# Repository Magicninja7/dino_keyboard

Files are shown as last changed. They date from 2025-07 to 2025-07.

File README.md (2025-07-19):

# Description
A keyboard with 84 keys, a ssd1306 mini-display, and 2 ec11 potentiometers. It has a unque look, with lots of extra keys for ex. undo, copy, paste, print, etc. You can also control the brightness and volume with the knobs (yes, i change the brightness that often).
Why? i literally thought: hmm, a keyboard would look nice on my desk. And highway happened, so i actually did it! 

### CAD render
render
### PCB
pcb
### diagram
diagram

# BOM
| item | price | quantity | total | link |
| --- | --- | --- | ----- | ---- |
| ssd1306 | 2$ | 1 | 2$ | https://pl.aliexpress.com/item/1005007755490093.html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 |
| cherry mx switch | 33$ | 90 | 33$ | https://pl.aliexpress.com/item/1005007907313874.html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
| keycaps | 25$ | 125 | 25$ | https://www.ebay.com/itm/374554619019?var=643532147086&utm_source=chatgpt.com
| raspi pico | - | 2 | - | - |
| EC11 rotary encoder | 1$ | 2 | 2$ | https://kamami.pl/enkodery/1191644-modul-encoder-impulsator-ec11-20-impulsow-z-przyciskiem-rotary-enkoder-5906623487332.html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
| PCB | 45$ | 1 | 45$ | n/d

total w/ customs & shipping = ~150$  (yay customs & shipping costs, how lovely)

Note: the places where i placed -, means i already have that part so i don't need to purchase it

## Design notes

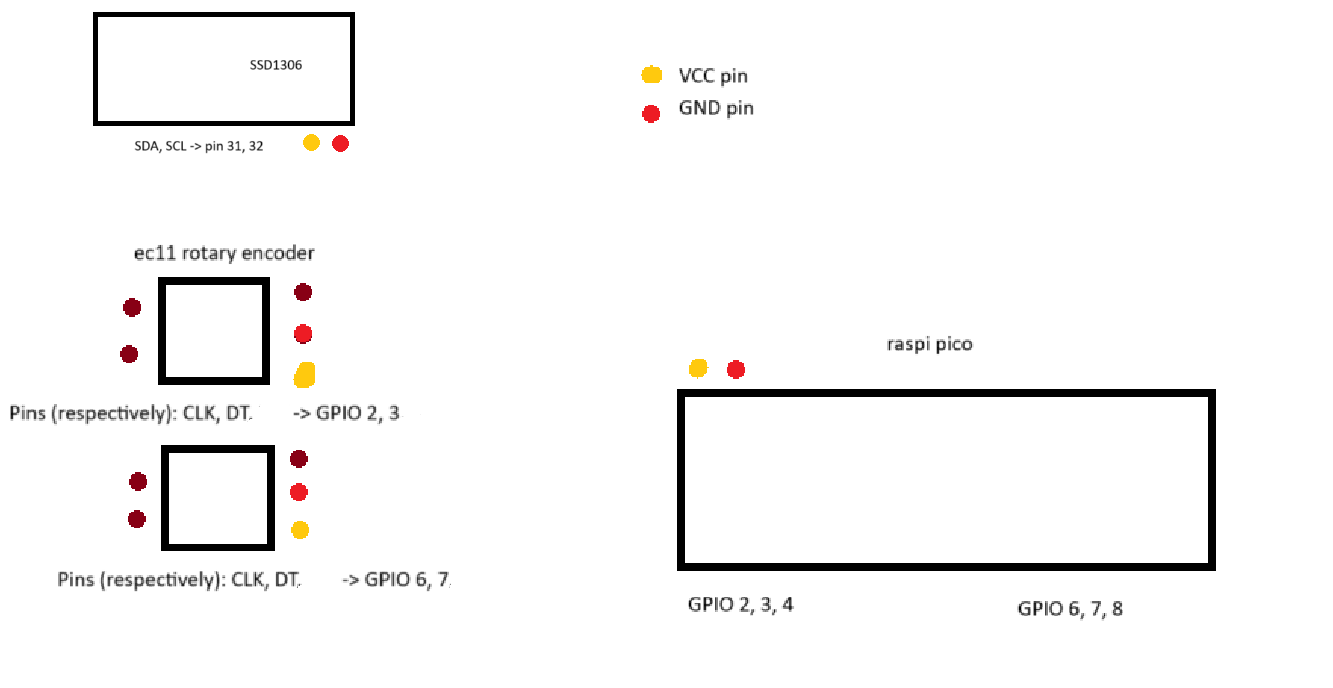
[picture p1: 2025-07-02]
diagram.png

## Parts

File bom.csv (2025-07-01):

item | price | quantity | total | link
ssd1306 | 2 | 1 | 2 | https://pl.aliexpress.com/item/1005007755490093.html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
cherry_mx_switch | 33 | 90 | 33 | https://pl.aliexpress.com/item/1005007907313874.html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
keycaps | 25 | 125 | 25 | https://www.ebay.com/itm/374554619019?var=643532147086&utm_source=chatgpt.com
raspi_pico | 8 | 2 | 16 | https://botland.com.pl/moduly-i-zestawy-do-raspberry-pi-pico/21574-raspberry-pi-pico-w-rp2040-arm-cortex-m0-cyw43439-wifi-5056561803173.html
ec11 | 1 | 2 | 2 | https://kamami.pl/enkodery/1191644-modul-encoder-impulsator-ec11-20-impulsow-z-przyciskiem-rotary-enkoder-5906623487332.html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
pcb | 45 | 1 | 45 | n/d

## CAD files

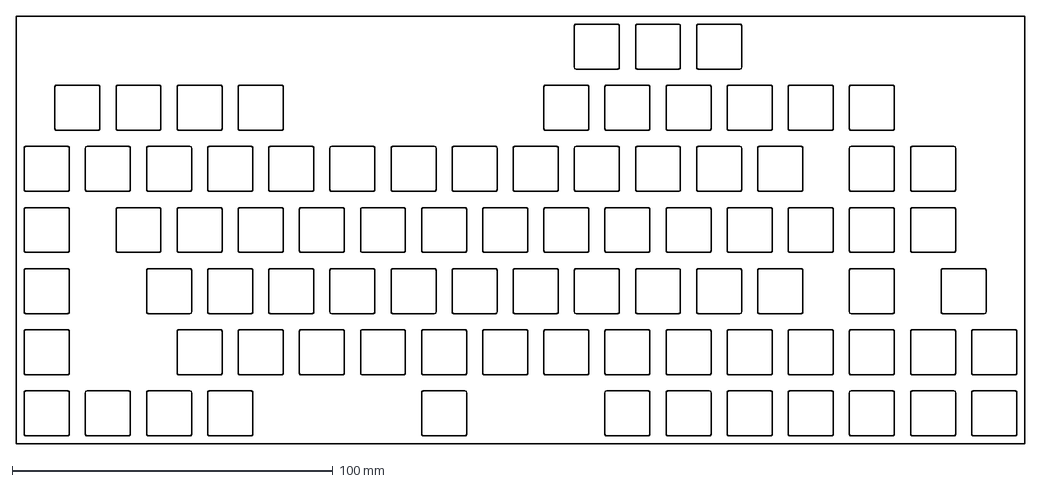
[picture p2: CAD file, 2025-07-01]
cad/plate-2025-05-24T16_50_25.808Z.dxf
314.3 x 133.3 mm

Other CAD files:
cad/EC11 Rotary Encoder Dode Switch-15mm .STEP
plate-2025-05-24T16_50_25.808Z.dxf

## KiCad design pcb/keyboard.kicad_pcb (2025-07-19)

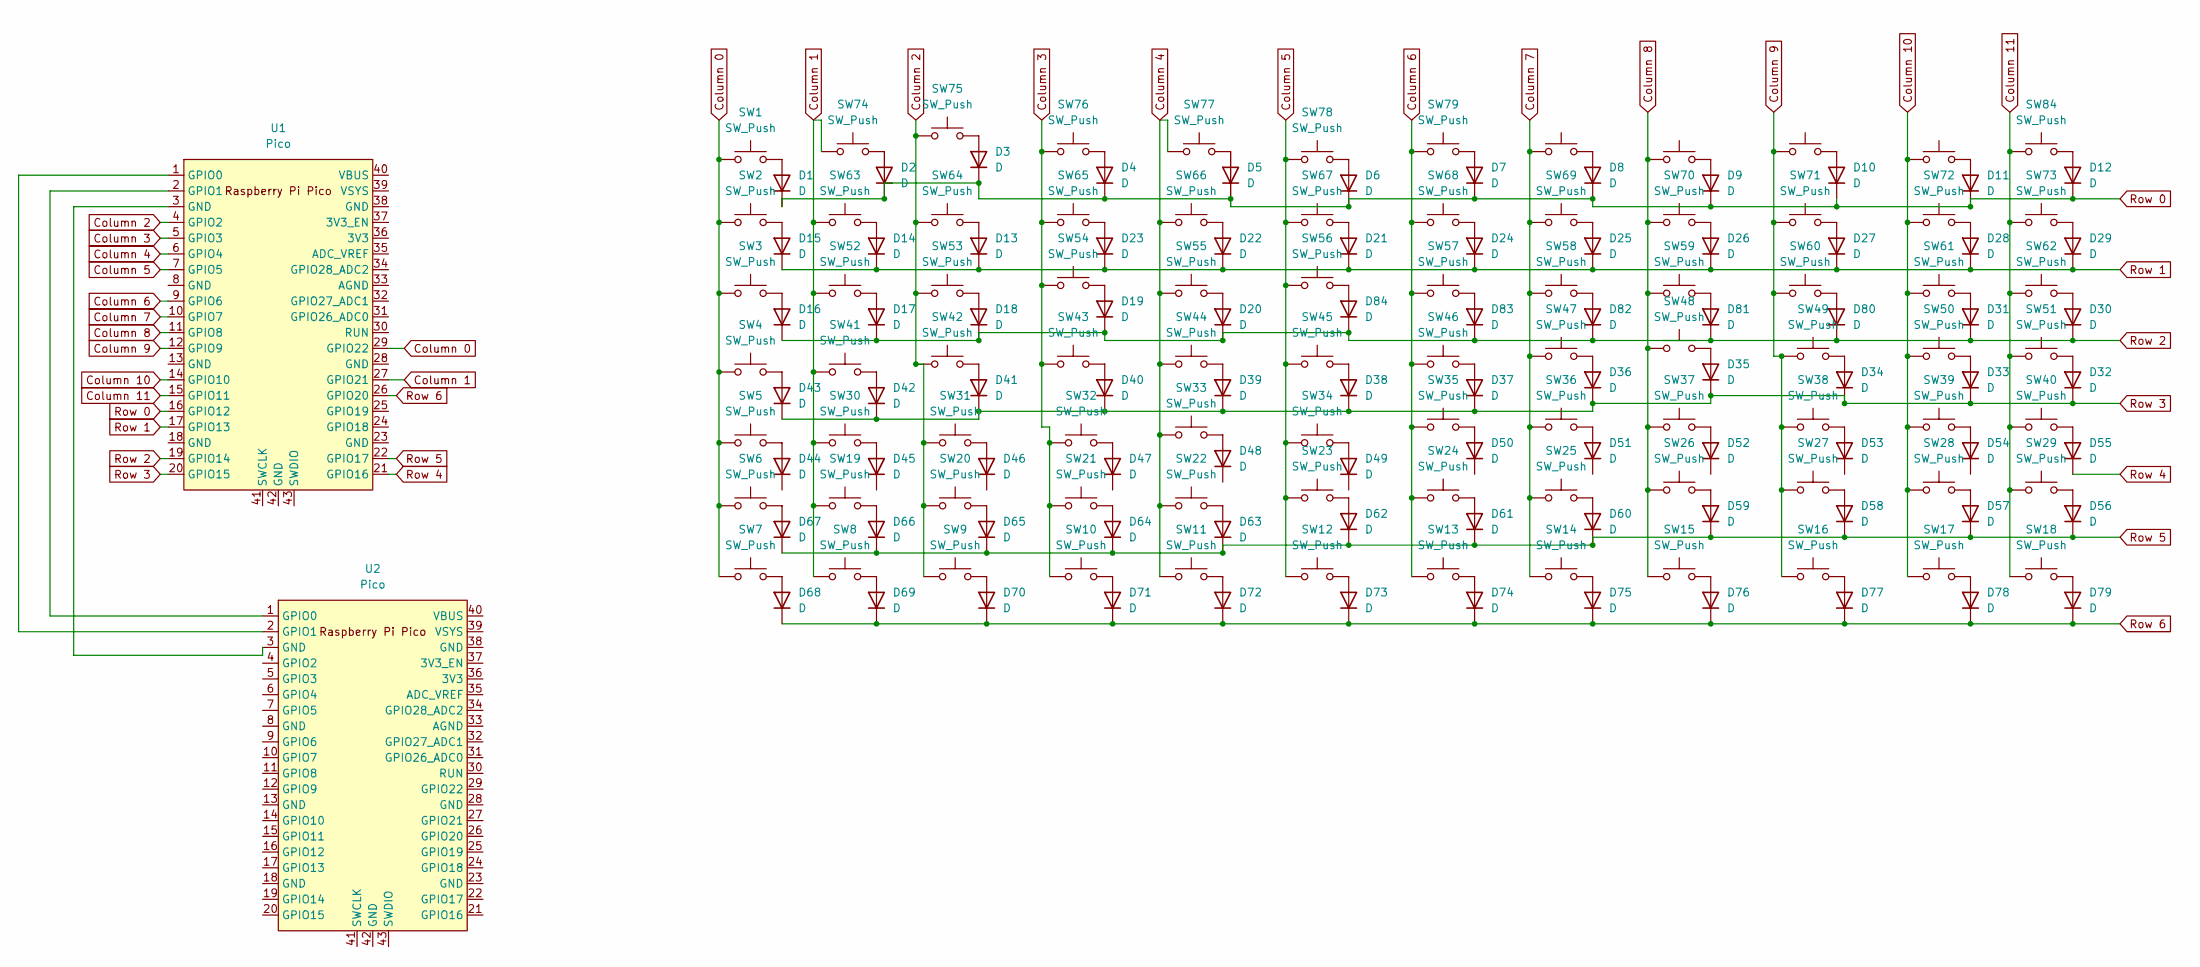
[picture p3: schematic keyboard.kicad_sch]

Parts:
D1, D2, D3, D4, D5, D6, D7, D8, D9, D10, D11, D12, D13, D14, D15, D16, D17, D18, D19, D20, D21, D22, D23, D24, D25, D26, D27, D28, D29, D30, D31, D32, D33, D34, D35, D36, D37, D38, D39, D40, D41, D42, D43, D44, D45, D46, D47, D48, D49, D50, D51, D52, D53, D54, D55, D56, D57, D58, D59, D60, D61, D62, D63, D64, D65, D66, D67, D68, D69, D70, D71, D72, D73, D74, D75, D76, D77, D78, D79, D80, D81, D82, D83, D84: D; LED_0201_0603Metric
SW1, SW2, SW3, SW4, SW5, SW6, SW7, SW8, SW9, SW10, SW11, SW12, SW13, SW14, SW15, SW16, SW17, SW18, SW19, SW20, SW21, SW22, SW23, SW24, SW25, SW26, SW27, SW28, SW29, SW30, SW31, SW32, SW33, SW34, SW35, SW36, SW37, SW38, SW39, SW40, SW41, SW42, SW43, SW44, SW45, SW46, SW47, SW48, SW49, SW52, SW53, SW54, SW55, SW56, SW57, SW58, SW60, SW61, SW62, SW63, SW64, SW65, SW66, SW67, SW68, SW69, SW70, SW71, SW72, SW73, SW74, SW75, SW76, SW77, SW78, SW79, SW80, SW81, SW82, SW83, SW84: SW_Push; SW_Cherry_MX_1.00u_PCB
SW50, SW51: SW_Push; SW_Cherry_MX_1.75u_PCB
SW59: SW_Push; SW_Cherry_MX_2.75u_PCB
U1, U2: Pico; RPi_Pico_SMD_TH

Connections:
Column 0: SW1.1, SW2.1, SW3.1, SW4.1, SW5.1, SW6.1, SW7.1, U1.29 (GPIO22)
Column 1: SW8.1, SW19.1, SW30.1, SW41.1, SW52.1, SW63.1, SW74.1, U1.27 (GPIO21)
Column 2: SW9.1, SW20.1, SW31.1, SW42.1, SW53.1, SW64.1, SW75.1, U1.4 (GPIO2)
Column 3: SW10.1, SW21.1, SW32.1, SW43.1, SW54.1, SW65.1, SW76.1, U1.5 (GPIO3)
Column 4: SW11.1, SW22.1, SW33.1, SW44.1, SW55.1, SW66.1, SW77.1, U1.6 (GPIO4)
Column 5: SW12.1, SW23.1, SW34.1, SW45.1, SW56.1, SW67.1, SW78.1, U1.7 (GPIO5)
Column 6: SW13.1, SW24.1, SW35.1, SW46.1, SW57.1, SW68.1, SW79.1, U1.9 (GPIO6)
Column 7: SW14.1, SW25.1, SW36.1, SW47.1, SW58.1, SW69.1, SW80.1, U1.10 (GPIO7)
Column 8: SW15.1, SW26.1, SW37.1, SW48.1, SW59.1, SW70.1, SW81.1, U1.11 (GPIO8)
Column 9: SW16.1, SW27.1, SW38.1, SW49.1, SW60.1, SW71.1, SW82.1, U1.12 (GPIO9)
Column 10: SW17.1, SW28.1, SW39.1, SW50.1, SW61.1, SW72.1, SW83.1, U1.14 (GPIO10)
Column 11: SW18.1, SW29.1, SW40.1, SW51.1, SW62.1, SW73.1, SW84.1, U1.15 (GPIO11)
unnamed: D1.2 (A), SW1.2
unnamed: D2.2 (A), SW74.2
unnamed: D3.2 (A), SW75.2
unnamed: D4.2 (A), SW76.2
unnamed: D5.2 (A), SW77.2
unnamed: D6.2 (A), SW78.2
unnamed: D7.2 (A), SW79.2
unnamed: D8.2 (A), SW80.2
unnamed: D9.2 (A), SW81.2
unnamed: D10.2 (A), SW82.2
unnamed: D11.2 (A), SW83.2
unnamed: D12.2 (A), SW84.2
unnamed: D13.2 (A), SW64.2
unnamed: D14.2 (A), SW63.2
unnamed: D15.2 (A), SW2.2
unnamed: D16.2 (A), SW3.2
unnamed: D17.2 (A), SW52.2
unnamed: D18.2 (A), SW53.2
unnamed: D19.2 (A), SW54.2
unnamed: D20.2 (A), SW55.2
unnamed: D21.2 (A), SW67.2
unnamed: D22.2 (A), SW66.2
unnamed: D23.2 (A), SW65.2
unnamed: D24.2 (A), SW68.2
unnamed: D25.2 (A), SW69.2
unnamed: D26.2 (A), SW70.2
unnamed: D27.2 (A), SW71.2
unnamed: D28.2 (A), SW72.2
unnamed: D29.2 (A), SW73.2
unnamed: D30.2 (A), SW62.2
unnamed: D31.2 (A), SW61.2
unnamed: D32.2 (A), SW51.2
unnamed: D33.2 (A), SW50.2
unnamed: D34.2 (A), SW49.2
unnamed: D35.2 (A), SW48.2
unnamed: D36.2 (A), SW47.2
unnamed: D37.2 (A), SW46.2
unnamed: D38.2 (A), SW45.2
unnamed: D39.2 (A), SW44.2
unnamed: D40.2 (A), SW43.2
unnamed: D41.2 (A), SW42.2
unnamed: D42.2 (A), SW41.2
unnamed: D43.2 (A), SW4.2
unnamed: D44.2 (A), SW5.2
unnamed: D45.2 (A), SW30.2
unnamed: D46.2 (A), SW31.2
unnamed: D47.2 (A), SW32.2
unnamed: D48.2 (A), SW33.2
unnamed: D49.2 (A), SW34.2
unnamed: D50.2 (A), SW35.2
unnamed: D51.2 (A), SW36.2
unnamed: D52.2 (A), SW37.2
unnamed: D53.2 (A), SW38.2
unnamed: D54.2 (A), SW39.2
unnamed: D55.2 (A), SW40.2
unnamed: D56.2 (A), SW29.2
unnamed: D57.2 (A), SW28.2
unnamed: D58.2 (A), SW27.2
unnamed: D59.2 (A), SW26.2
unnamed: D60.2 (A), SW25.2
unnamed: D61.2 (A), SW24.2
unnamed: D62.2 (A), SW23.2
unnamed: D63.2 (A), SW22.2
unnamed: D64.2 (A), SW21.2
unnamed: D65.2 (A), SW20.2
unnamed: D66.2 (A), SW19.2
unnamed: D67.2 (A), SW6.2
unnamed: D68.2 (A), SW7.2
unnamed: D69.2 (A), SW8.2
unnamed: D70.2 (A), SW9.2
unnamed: D71.2 (A), SW10.2
unnamed: D72.2 (A), SW11.2
unnamed: D73.2 (A), SW12.2
unnamed: D74.2 (A), SW13.2
unnamed: D75.2 (A), SW14.2
unnamed: D76.2 (A), SW15.2
unnamed: D77.2 (A), SW16.2
unnamed: D78.2 (A), SW17.2
unnamed: D79.2 (A), SW18.2
unnamed: D80.2 (A), SW60.2
unnamed: D81.2 (A), SW59.2
unnamed: D82.2 (A), SW58.2
unnamed: D83.2 (A), SW57.2
unnamed: D84.2 (A), SW56.2
unnamed: U1.3 (GND), U2.3 (GND)
unnamed: U1.1 (GPIO0), U2.2 (GPIO1)
unnamed: U1.2 (GPIO1), U2.1 (GPIO0)
Row 0: D1.1 (K), D2.1 (K), D3.1 (K), D4.1 (K), D5.1 (K), D6.1 (K), D7.1 (K), D8.1 (K), D9.1 (K), D10.1 (K), D11.1 (K), D12.1 (K), U1.16 (GPIO12)
Row 1: D13.1 (K), D14.1 (K), D15.1 (K), D21.1 (K), D22.1 (K), D23.1 (K), D24.1 (K), D25.1 (K), D26.1 (K), D27.1 (K), D28.1 (K), D29.1 (K), U1.17 (GPIO13)
Row 2: D16.1 (K), D17.1 (K), D18.1 (K), D19.1 (K), D20.1 (K), D30.1 (K), D31.1 (K), D80.1 (K), D81.1 (K), D82.1 (K), D83.1 (K), D84.1 (K), U1.19 (GPIO14)
Row 3: D32.1 (K), D33.1 (K), D34.1 (K), D35.1 (K), D36.1 (K), D37.1 (K), D38.1 (K), D39.1 (K), D40.1 (K), D41.1 (K), D42.1 (K), D43.1 (K), U1.20 (GPIO15)
Row 4: D55.1 (K), U1.21 (GPIO16)
Row 5: D56.1 (K), D57.1 (K), D58.1 (K), D59.1 (K), D60.1 (K), D61.1 (K), D62.1 (K), D63.1 (K), D64.1 (K), D65.1 (K), D66.1 (K), D67.1 (K), U1.22 (GPIO17)
Row 6: D68.1 (K), D69.1 (K), D70.1 (K), D71.1 (K), D72.1 (K), D73.1 (K), D74.1 (K), D75.1 (K), D76.1 (K), D77.1 (K), D78.1 (K), D79.1 (K), U1.26 (GPIO20)

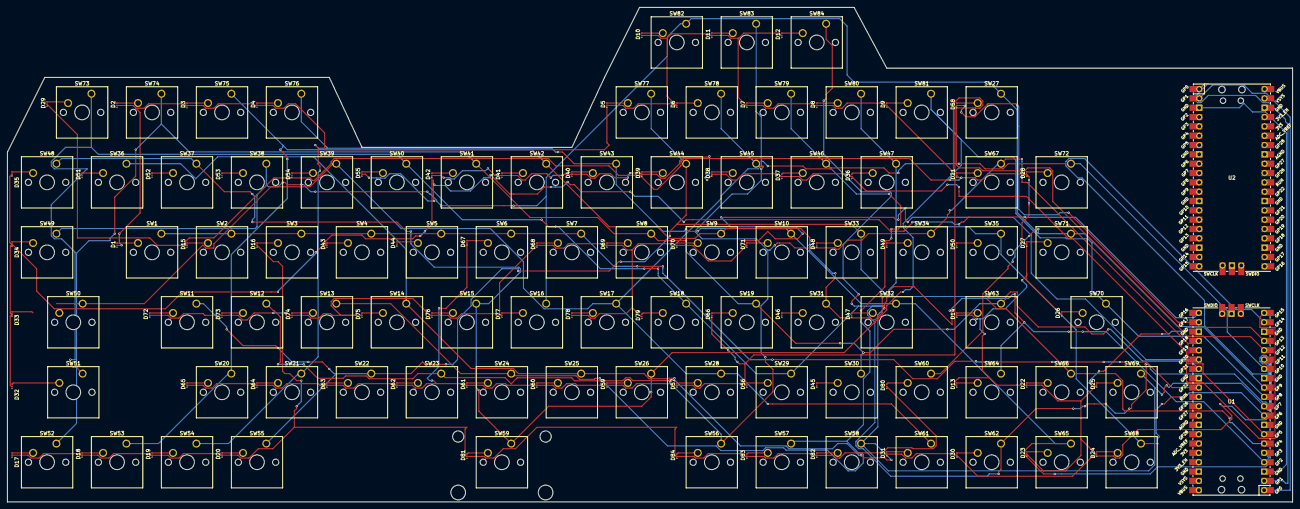
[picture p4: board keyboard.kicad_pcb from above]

Board: 2 copper layers, 349.9 x 134.6 mm, 170 parts (0 on the bottom side), 106 nets.

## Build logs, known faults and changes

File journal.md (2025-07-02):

**title**: DIno keyboard\
**author**: @Magic (slack)\
**description**: A completely custom keyboard!\
**created_at**: 21.05.2025\
**total time**: 34 hours

# Day 1 (19.05.2025) ~1hour
Created a folder for the project, and added symbols & footprints for both xiao and raspi microcontrollers. Watched a couple videos on how to make a key matrix, and not too long later, i started making the matrix


# Day 2 (21.05.2025) ~5hours
Today i finished the key matrix, and researched on how demanding would led matrixes be. due to gpio limitations, i switched to the raspi pico (originally used seeed rp2040 dip)
Afterward i researched a bit on how i can limit the number if gpio pins needed to create a led matrix. however i found no satisfactory one, so i just decided on a screen. But lcd are ugly, i hate the tint, slow speed, and small viewing angles. I found e-ink screens, and decided on using that one. i added it onto the scematics, alongside a handful of led.

After that i placed most of the keys, only leaving the top row (known as the f keys). i left the eink display and potentiometer out of the pcb (it will be in an alternate position). I also will add another pico, since the first one has to little gpio pins. (im writing this paragraph the day after)
keyboard-image

# Day 3 (22.05.25) ~3 hours
Now i have routed and placed everything, it was a big pain in the ass. The routing is ***very*** ugly, but it works, and its all that matters. I have also added the extra pico to the pcb. finally the pcb is finished.
pain and suffering

# Day 4 (23.05.25) ~3 hours
After making a almost complete 3d model for it, i realised the kays are slightly tilted, so i went back and deleted it, and remade it.
more pain

# Day 5 (24.05.25) ~5 hours
Today i made the keyboard in fusion, creating the case, adding the top layer, pasting the pcb, and adding the rest of the parts. I also added 2x rotary encoders, 1x slider, and changed from the eink screen to the ssd1306. The reason? easier coding & wiring and alright contrast. I also decided on a slightly different design, not the classic 75%, but with more keys, with massively different positioning.


# Day 6 (25.05.25) ~5 hours
Made an attempt at using qmk configurator, and python. both ended in a loss. Now im setting up QMK, and am reading the docs, and watching videos and reading over templates, while making a draft of my own.


# Day 7 (30.06.25) ~8 hours
F me im still doing qmk. Today i coded like 5 version, all of which failed. At first i even created a nicely drawn keyboard, and made 4 layers, but noooo. Got errors till i gave up, and stated deleting problematic things. In times of desperation, i turned to reddit, and after 200 views, im yet to get a response. 
Anyway, after 9 hours of debugging, sorry, **trying to debug** i decided on polishing the cad instead. So while waiting for my answer from reddit or #code, i smoothed out the edges, and fixed tons of small 0.1 mm errors. Note: i will continue working on the firmware, once i make the keyboard, since my matrix is pretty messed up, so even if qmk compiles, im not sure if it'd work correctly.
look
this is the most simple, cut down version of QMK i now have, and it still doesnt work.
bs
And scratch the b10k, i don't have the correct pins necessary.

# Day 8 (02.07.25) ~4 hours
At last, after help from some fellow redditors, i managed to get it to work. I also made the animation for the ssd1306, hich is a running dino, from the chrome easter egg.



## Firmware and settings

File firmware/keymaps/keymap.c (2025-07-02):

#include QMK_KEYBOARD_H

#if defined(ENCODER_MAP_ENABLE)
const uint16_t PROGMEM encoder_map[][2][2] = {
    [0] =  { ENCODER_CCW_CW(KC_VOLD, KC_VOLU), ENCODER_CCW_CW(KC_BRIU, KC_BRID)},
};
#endif


const uint16_t PROGMEM keymaps[][MATRIX_ROWS][MATRIX_COLS] = {

    [0] = LAYOUT(
        KC_ESC,   KC_1,    KC_2,    KC_3,    KC_4,    KC_5,    KC_6,    KC_7,    KC_8,    KC_9,    KC_0,    KC_BSPC,
        KC_TAB,   KC_Q,    KC_W,    KC_E,    KC_R,    KC_T,    KC_Y,    KC_U,    KC_I,    KC_O,    KC_P,    KC_BSLS,
        KC_CAPS,  KC_A,    KC_S,    KC_D,    KC_F,    KC_G,    KC_H,    KC_J,    KC_K,    KC_L,    KC_SCLN, KC_QUOT,
        KC_LSFT,  KC_Z,    KC_X,    KC_C,    KC_V,    KC_B,    KC_N,    KC_M,    KC_COMM, KC_DOT,  KC_SLSH, KC_RSFT,
        KC_LCTL,  KC_LGUI, KC_LALT, KC_SPC,  KC_SPC,  KC_SPC,  KC_SPC,  KC_SPC,  KC_SPC,  KC_RALT, KC_RGUI, KC_RCTL,
        KC_F1,    KC_F2,   KC_F3,   KC_F4,   KC_F5,   KC_F6,   KC_F7,   KC_F8,   KC_F9,   KC_F10,  KC_F11,  KC_F12,
        KC_LCTL,  KC_LGUI, KC_SPC, KC_MUTE, KC_DEL,  KC_LEFT, KC_DOWN, KC_UP,   KC_RIGHT,  TG(1),   KC_RCTL, KC_RALT
    ),

};



#ifdef OLED_ENABLE

#define FRAME_DURATION 100
const uint16_t frame_sizes[5] = {1040, 1040, 1040, 1040, 1040};

uint32_t timer = 0;
uint8_t current_frame = 0;

static void render_animation(void) {
    // 'frame_0_delay-0', 128x64px

// 'Screenshot 2025-07-02 113608', 128x64px
const unsigned char epd_bitmap_Screenshot_2025_07_02_113608 [] PROGMEM = {
	0x00, 0x00, 0x00, 0x03, 0xff, 0xff, 0xff, 0xff, 0xff, 0xff, 0xff, 0xff, 0xe0, 0x00, 0x00, 0x00, 
	0x00, 0x00, 0x00, 0x03, 0xff, 0xff, 0xff, 0xff, 0xff, 0xff, 0xff, 0xff, 0xe0, 0x00, 0x00, 0x00, 
	0x00, 0x00, 0x00, 0x03, 0xff, 0xff, 0xff, 0xff, 0xff, 0xff, 0xff, 0xff, 0xe0, 0x00, 0x00, 0x00, 
	0x00, 0x00, 0x00, 0x03, 0xff, 0xff, 0xff, 0xff, 0xff, 0xff, 0xff, 0xff, 0xe0, 0x00, 0x00, 0x00, 
	0x00, 0x00, 0x00, 0x03, 0xff, 0xff, 0xff, 0xff, 0xff, 0xff, 0xff, 0xff, 0xe0, 0x00, 0x00, 0x00, 
	0x00, 0x00, 0x00, 0x03, 0xff, 0xff, 0xff, 0xff, 0xff, 0xff, 0xff, 0xff, 0xe0, 0x00, 0x00, 0x00, 
	0x00, 0x00, 0x00, 0x03, 0xff, 0xff, 0xff, 0xff, 0xff, 0xff, 0xff, 0xff, 0xe0, 0x00, 0x00, 0x00, 
	0x00, 0x00, 0x00, 0x03, 0xff, 0xff, 0xff, 0xff, 0xff, 0xff, 0xff, 0xff, 0xe0, 0x00, 0x00, 0x00, 
	0x00, 0x00, 0x00, 0x03, 0xff, 0xff, 0xff, 0xff, 0xff, 0xff, 0xff, 0xff, 0xe0, 0x00, 0x00, 0x00, 
	0x00, 0x00, 0x00, 0x03, 0xff, 0xff, 0xff, 0xff, 0xff, 0xff, 0xff, 0xff, 0xe0, 0x00, 0x00, 0x00, 
	0x00, 0x00, 0x00, 0x03, 0xff, 0xff, 0xff, 0xff, 0xff, 0xff, 0xff, 0xff, 0xe0, 0x00, 0x00, 0x00, 
	0x00, 0x00, 0x00, 0x03, 0xff, 0xff, 0xff, 0xff, 0xff, 0xff, 0xff, 0xff, 0xe0, 0x00, 0x00, 0x00, 
	0x00, 0x00, 0x00, 0x03, 0xff, 0xff, 0xff, 0xff, 0xc0, 0x00, 0x3f, 0xff, 0xe0, 0x00, 0x00, 0x00, 
	0x00, 0x00, 0x00, 0x03, 0xff, 0xff, 0xff, 0xff, 0xc0, 0x00, 0x3f, 0xff, 0xe0, 0x00, 0x00, 0x00, 
	0x00, 0x00, 0x00, 0x03, 0xff, 0xff, 0xff, 0xff, 0x0c, 0x00, 0x0f, 0xff, 0xe0, 0x00, 0x00, 0x00, 
	0x00, 0x00, 0x00, 0x03, 0xff, 0xff, 0xff, 0xff, 0x0c, 0x00, 0x0f, 0xff, 0xe0, 0x00, 0x00, 0x00, 
	0x00, 0x00, 0x00, 0x03, 0xff, 0xff, 0xff, 0xff, 0x0c, 0x00, 0x0f, 0xff, 0xe0, 0x00, 0x00, 0x00, 
	0x00, 0x00, 0x00, 0x03, 0xff, 0xff, 0xff, 0xff, 0x00, 0x00, 0x0f, 0xff, 0xe0, 0x00, 0x00, 0x00, 
	0x00, 0x00, 0x00, 0x03, 0xff, 0xff, 0xff, 0xff, 0x00, 0x00, 0x0f, 0xff, 0xe0, 0x00, 0x00, 0x00, 
	0x00, 0x00, 0x00, 0x03, 0xff, 0xff, 0xff, 0xff, 0x00, 0x00, 0x0f, 0xff, 0xe0, 0x00, 0x00, 0x00, 
	0x00, 0x00, 0x00, 0x03, 0xff, 0xff, 0xff, 0xff, 0x00, 0x00, 0x0f, 0xff, 0xe0, 0x00, 0x00, 0x00, 
	0x00, 0x00, 0x00, 0x03, 0xff, 0xff, 0xff, 0xff, 0x00, 0x00, 0x0f, 0xff, 0xe0, 0x00, 0x00, 0x00, 
	0x00, 0x00, 0x00, 0x03, 0xff, 0xff, 0xff, 0xff, 0x00, 0x3f, 0xff, 0xff, 0xe0, 0x00, 0x00, 0x00, 
	0x00, 0x00, 0x00, 0x03, 0xff, 0xff, 0xff, 0xff, 0x00, 0x3f, 0xff, 0xff, 0xe0, 0x00, 0x00, 0x00, 
	0x00, 0x00, 0x00, 0x03, 0xff, 0xff, 0xff, 0xff, 0x00, 0x3f, 0xff, 0xff, 0xe0, 0x00, 0x00, 0x00, 
	0x00, 0x00, 0x00, 0x03, 0xff, 0xff, 0xff, 0xff, 0x00, 0x00, 0xff, 0xff, 0xe0, 0x00, 0x00, 0x00, 
	0x00, 0x00, 0x00, 0x03, 0xff, 0xff, 0xff, 0xff, 0x00, 0xff, 0xff, 0xff, 0xe0, 0x00, 0x00, 0x00, 
	0x00, 0x00, 0x00, 0x03, 0xff, 0xf3, 0xff, 0xfc, 0x00, 0xff, 0xff, 0xff, 0xe0, 0x00, 0x00, 0x00, 
	0x00, 0x00, 0x00, 0x03, 0xff, 0xf3, 0xff, 0xfc, 0x00, 0xff, 0xff, 0xff, 0xe0, 0x00, 0x00, 0x00, 
	0x00, 0x00, 0x00, 0x03, 0xff, 0xf3, 0xff, 0xe0, 0x00, 0xff, 0xff, 0xff, 0xe0, 0x00, 0x00, 0x00, 
	0x00, 0x00, 0x00, 0x03, 0xff, 0xf3, 0xff, 0xe0, 0x00, 0xff, 0xff, 0xff, 0xe0, 0x00, 0x00, 0x00, 
	0x00, 0x00, 0x00, 0x03, 0xff, 0xf0, 0xff, 0x00, 0x00, 0x0f, 0xff, 0xff, 0xe0, 0x00, 0x00, 0x00, 
	0x00, 0x00, 0x00, 0x03, 0xff, 0xf0, 0xff, 0x00, 0x00, 0xcf, 0xff, 0xff, 0xe0, 0x00, 0x00, 0x00, 
	0x00, 0x00, 0x00, 0x03, 0xff, 0xf0, 0x3c, 0x00, 0x00, 0xcf, 0xff, 0xff, 0xe0, 0x00, 0x00, 0x00, 
	0x00, 0x00, 0x00, 0x03, 0xff, 0xf0, 0x3c, 0x00, 0x00, 0xff, 0xff, 0xff, 0xe0, 0x00, 0x00, 0x00, 
	0x00, 0x00, 0x00, 0x03, 0xff, 0xf0, 0x00, 0x00, 0x00, 0xff, 0xff, 0xff, 0xe0, 0x00, 0x00, 0x00, 
	0x00, 0x00, 0x00, 0x03, 0xff, 0xf0, 0x00, 0x00, 0x00, 0xff, 0xff, 0xff, 0xe0, 0x00, 0x00, 0x00, 
	0x00, 0x00, 0x00, 0x03, 0xff, 0xf0, 0x00, 0x00, 0x00, 0xff, 0xff, 0xff, 0xe0, 0x00, 0x00, 0x00, 
	0x00, 0x00, 0x00, 0x03, 0xff, 0xfc, 0x00, 0x00, 0x00, 0xff, 0xff, 0xff, 0xe0, 0x00, 0x00, 0x00, 
	0x00, 0x00, 0x00, 0x03, 0xff, 0xfc, 0x00, 0x00, 0x03, 0xff, 0xff, 0xff, 0xe0, 0x00, 0x00, 0x00, 
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
};
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

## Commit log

2025-07-01 Update and rename keyboard.kicad_sch to pcb/keyboard.kicad_sch
    [keyboard.kicad_sch]
2025-07-01 Update and rename keyboard.kicad_pcb to pcb/keyboard.kicad_pcb
    [keyboard.kicad_pcb]
2025-07-01 Rename EC11 Rotary Encoder Dode Switch-15mm .STEP to cad/EC11 Rotary Encoder Dode Switch-15mm .STEP
    [EC11 Rotary Encoder Dode Switch-15mm .STEP]
